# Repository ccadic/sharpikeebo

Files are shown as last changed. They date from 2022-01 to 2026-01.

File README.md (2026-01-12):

**SHARPIKEEBO – Version 2025 (Public Release)
**
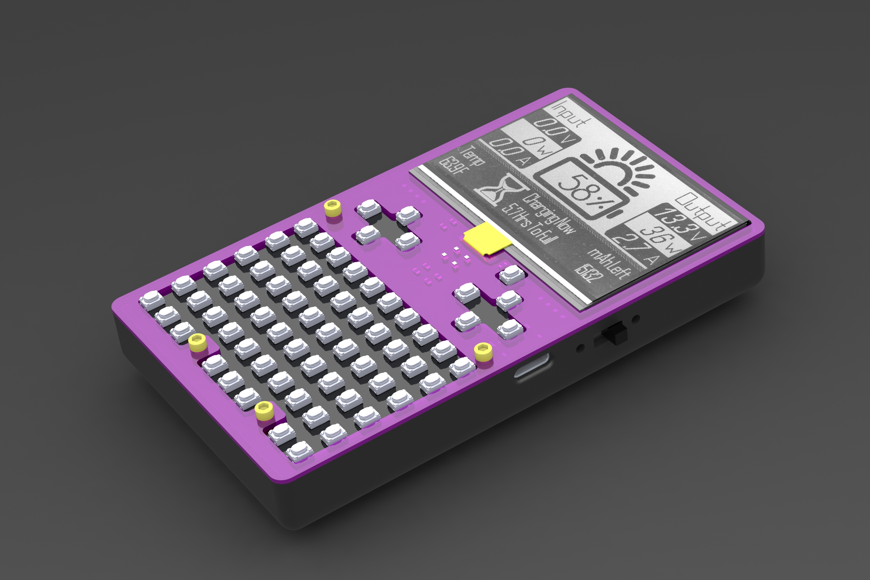
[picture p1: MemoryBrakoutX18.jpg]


**sharpikeebo – V2025
Miniature Raspberry Pi Zero 2W shield with Sharp Memory Display and USB Keyboard
**
This repository now documents the public 2025 version of the SHARPIKEEBO, distributed after the successful crowdfunding campaign on
Crowd Supply: https://www.crowdsupply.com/morpheans/sharpikeebo

All hardware described here corresponds to the final production version delivered to backers and the public.

Overview

Hello all,

This is the SHARPIKEEBO Nano Computer Shield, built around the famous Raspberry Pi Zero 2W, featuring:

- A high-quality Sharp Memory Display (400 × 240 pixels)
- A true USB keyboard, powered by QMK firmware
(https://docs.qmk.fm/#/)
- An ATmega32U4 microcontroller
- A compact form factor designed as a real miniature Linux terminal

The SHARPIKEEBO was initially designed as a portable SSH and system administration tool, allowing administrators to quickly connect to servers and perform maintenance operations.
During development, many users also pointed out its potential as a retro or lightweight gaming platform.

**Hardware Description
**

The SHARPIKEEBO carrier board is designed to host:

- A Raspberry Pi Zero 2W or Zero W
- A 2.7" Sharp Memory Display (400 × 240) capable of fast refresh rates, suitable for:
  Linux shells
  Text-based interfaces
  Simple graphical games
  Additional features include:

- Controllable LEDs (GPIO, usable from C++ or Python)
- Easily accessible UART and I²C GPIOs for external modules:
  GPS
  4G / 5G modem
  Other 3.3 V or 5 V peripherals

Power is supplied via USB-C, and the board can also behave as a USB keyboard device when plugged into a desktop, laptop, or rack server.

**IMPORTANT CHANGES & CLARIFICATION (READ CAREFULLY)
**
This section is critical for proper operation of the 2025 public hardware.

**Raspberry Pi Zero mounting orientation (VERY IMPORTANT)
**
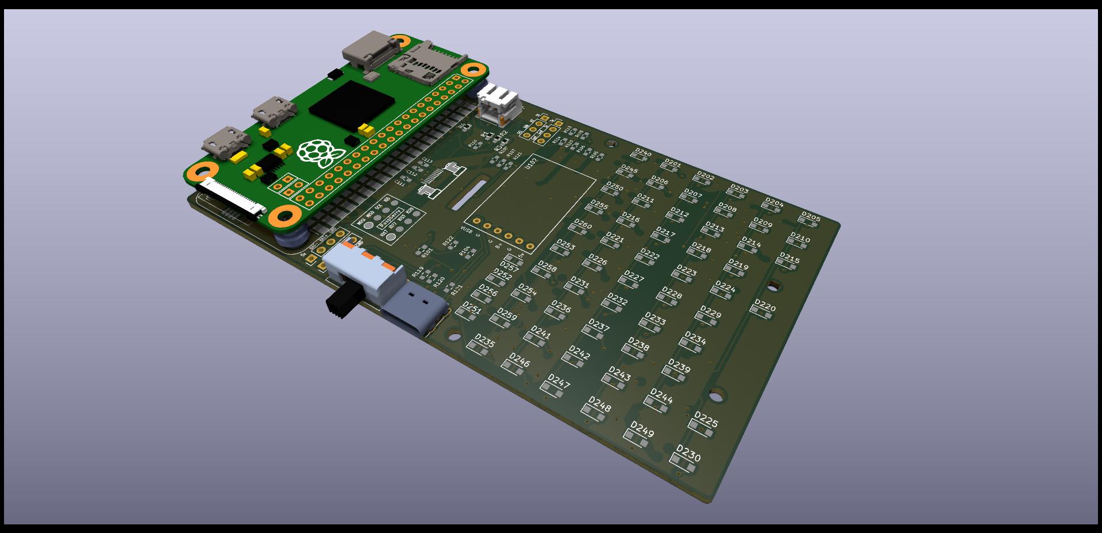
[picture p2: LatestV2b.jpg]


The Raspberry Pi Zero must be mounted with its connector facing DOWN

This means the components of the Raspberry Pi remain visible

DO NOT use a 20×2 pin header mounted on the TOP side

If the Raspberry Pi is connected using a top-mounted 20×2 pin header, the board will NOT work

 This is not optional and is required by the electrical design of the SHARPIKEEBO.

 Battery polarity warning
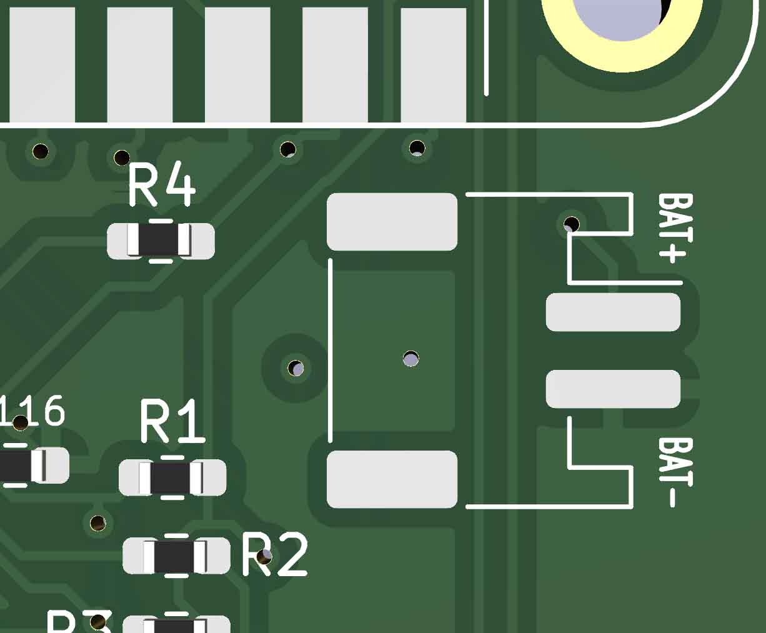
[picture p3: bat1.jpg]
**** 

Some batteries on the market do NOT follow standard polarity orientation

Incorrect polarity can permanently damage the board

 Always verify battery polarity against the schematics before connecting
 Never assume wire colors are correct

**RAK Wireless module interface
**
The RAK Wireless module is connected in UART mode

It is NOT wired in SPI mode

 Any software configuration must therefore use UART, not SPI.
Factory testing guarantee

Every single SHARPIKEEBO unit shipped has been individually tested

All boards were:
- Powered
- Verified
- Confirmed fully functional before shipping

If you encounter an issue, it is almost always related to:
- Incorrect Raspberry Pi mounting
- Battery polarity inversion
- Incorrect peripheral wiring or configuration
- Status

This repository now reflects the final, stable, production hardware shipped after the Crowd Supply campaign.
Future updates will focus on software examples, configurations, and community contributions, not hardware changes.

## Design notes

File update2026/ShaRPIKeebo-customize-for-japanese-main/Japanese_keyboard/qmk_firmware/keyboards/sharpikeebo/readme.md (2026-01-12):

# sharpikeebo

![sharpikeebo]

*A short description of the keyboard/project*

* Keyboard Maintainer: t.hara (https://github.com/hra1129)
* Hardware Supported: *The PCBs, controllers supported*
* Hardware Availability: *Links to where you can find this hardware*

Make example for this keyboard (after setting up your build environment):

    make sharpikeebo:default

Flashing example for this keyboard:

    make sharpikeebo:default:flash

See the [build environment setup](https://docs.qmk.fm/#/getting_started_build_tools) and the [make instructions](https://docs.qmk.fm/#/getting_started_make_guide) for more information. Brand new to QMK? Start with our [Complete Newbs Guide](https://docs.qmk.fm/#/newbs).

## Bootloader

Enter the bootloader in 3 ways:

* **Bootmagic reset**: Hold down the key at (0,0) in the matrix (usually the top left key or Escape) and plug in the keyboard
* **Physical reset button**: Briefly press the button on the back of the PCB - some may have pads you must short instead
* **Keycode in layout**: Press the key mapped to `RESET` if it is available

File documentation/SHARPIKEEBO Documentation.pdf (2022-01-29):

# SHARPIKEEBO 1.0

RASPBERRY PI ZERO + SHARP LS027B7DH01 Memory Display Carrier Board + USB ATMEGA34U Keyboard

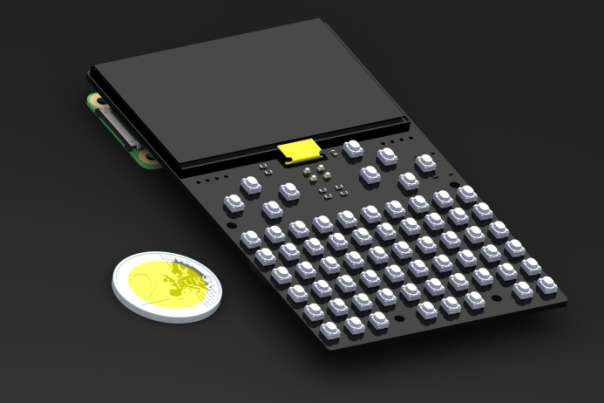
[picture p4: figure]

Description

The SHARPIKEEBO carrier board has been designed to hold both a Raspberry(R) PI ZERO 2W or W + 2.7" (400x240) Sharp Memory Display. This display is capable of a fast refresh which allows the use of linux shells or display game images. A true USB Keyboard (driven by QMK firmware, so fully customized) has been added on the board.

The board also has 4 independently controllable LEDs you can switch on/off with classic GPIO commands (C++ or Python)

The board also has 5 buttons you may also control via GPIO voltage detection (UP/Down voltage detection). You can use this board for gaming.

And more, you have UART GPIO and I2C GPIO easily available on board should you want to add a 3.3v or 5v module such a GPS , 4g or 5g modem etc ...

The board + RPI can be powered thought a USB C connector. The board has also been design to behave as a USB keyboard you can plug on a desktop or laptop or rack server.

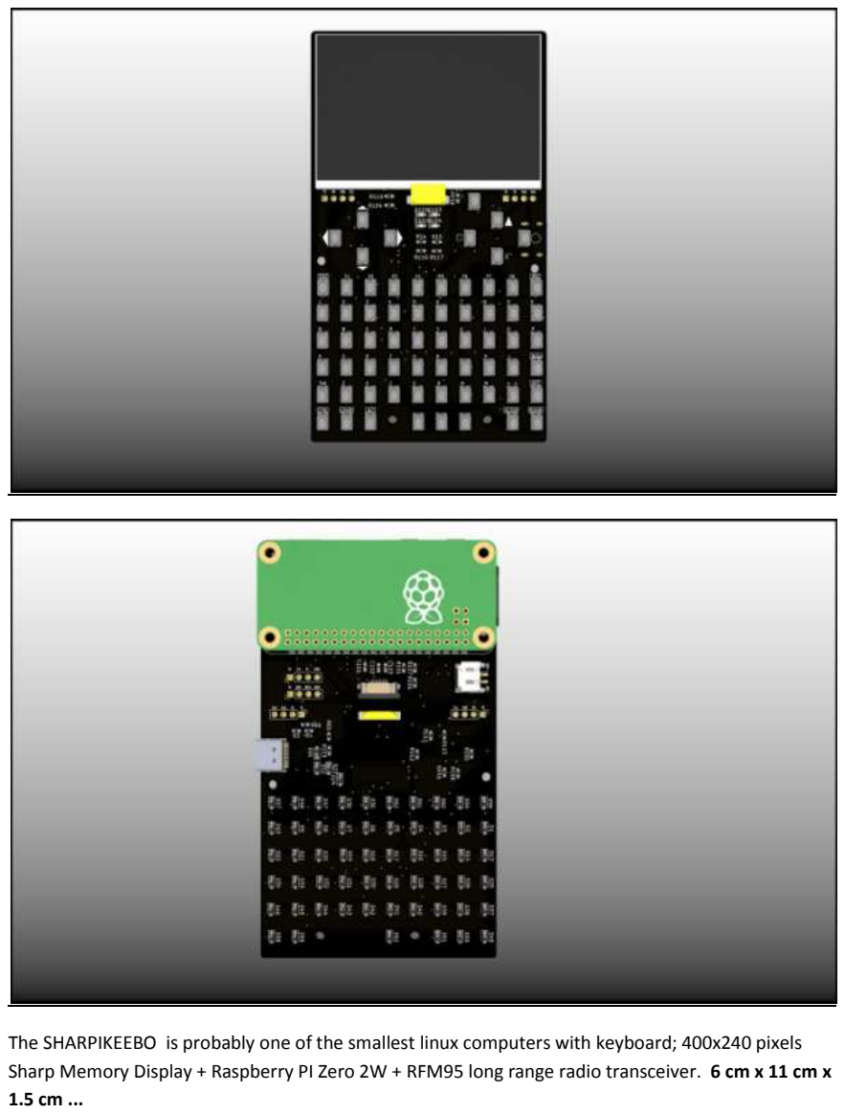
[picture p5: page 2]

The SHARPIKEEBO is probably one of the smallest linux computers with keyboard; 400x240 pixels Sharp Memory Display + Raspberry PI Zero 2W + RFM95 long range radio transceiver. 6 cm x 11 cm x 1.5 cm ...

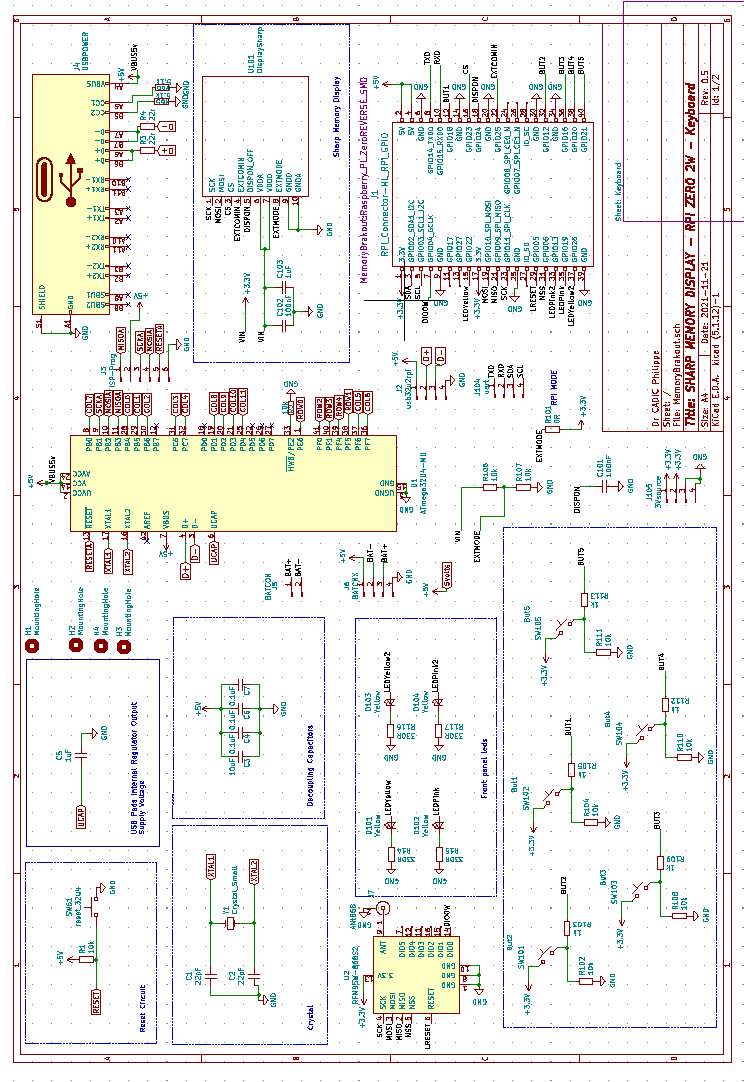
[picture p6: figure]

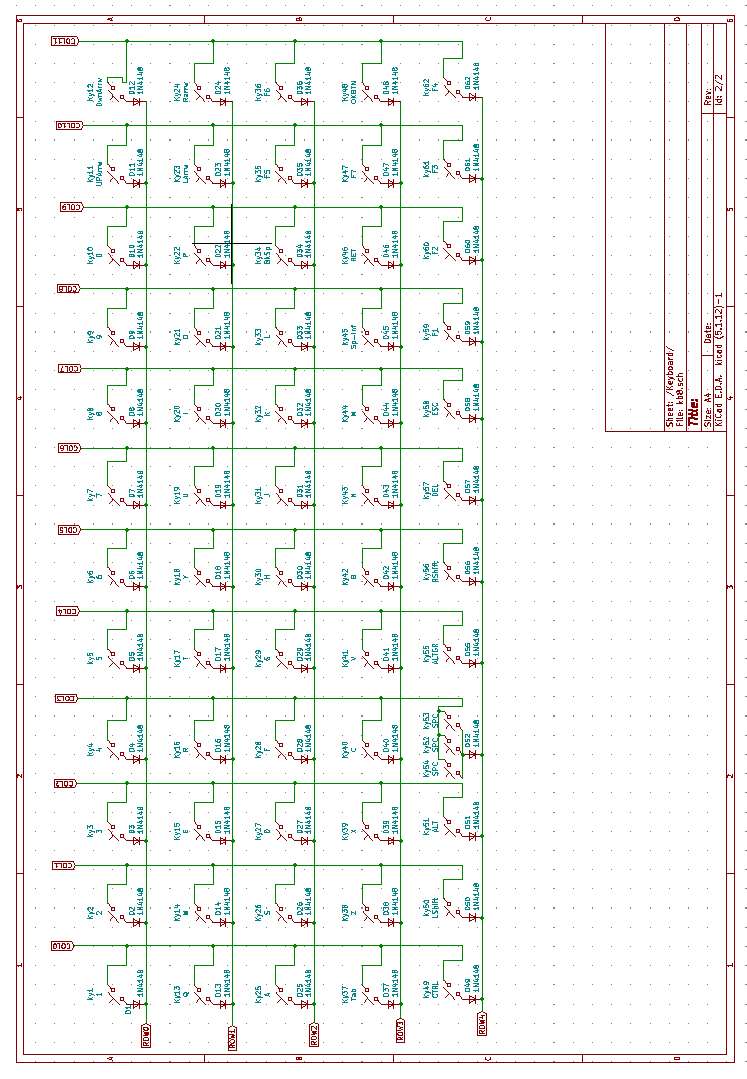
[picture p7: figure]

Extra GPIO available

We added several extra GPIO, should you want to add an external UART extra board or a I2C board. For the maker, we also added access to the display pins with the right bottom line of 2.54 mm header pinout (SCK to GND). If you want, you can drive the LCD without the Raspberry PI ZERO , and replace it with a classic microcontroller. In the same idea, you have B1 to B5 buttons signals available on pins.

You get all the necessary connectors to add a battery charger , should your want to add a lipo and build a autonomous device or drive a 3G/4G/5G modem which require a lipo for energy reasons.

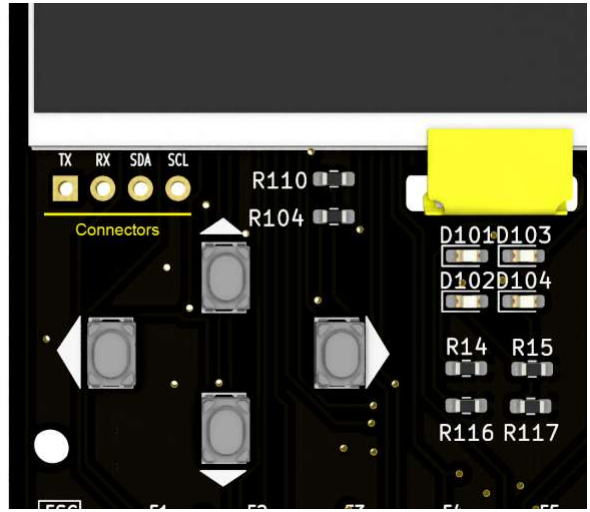
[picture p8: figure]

On the left you get 4 pins to connect a UART optional module or an I2C sister board. For example, you can add an optional display with the I2C interface, a GSM module such as SIM800L or newer which is often compatible with UART, an accelerometer … etc etc …

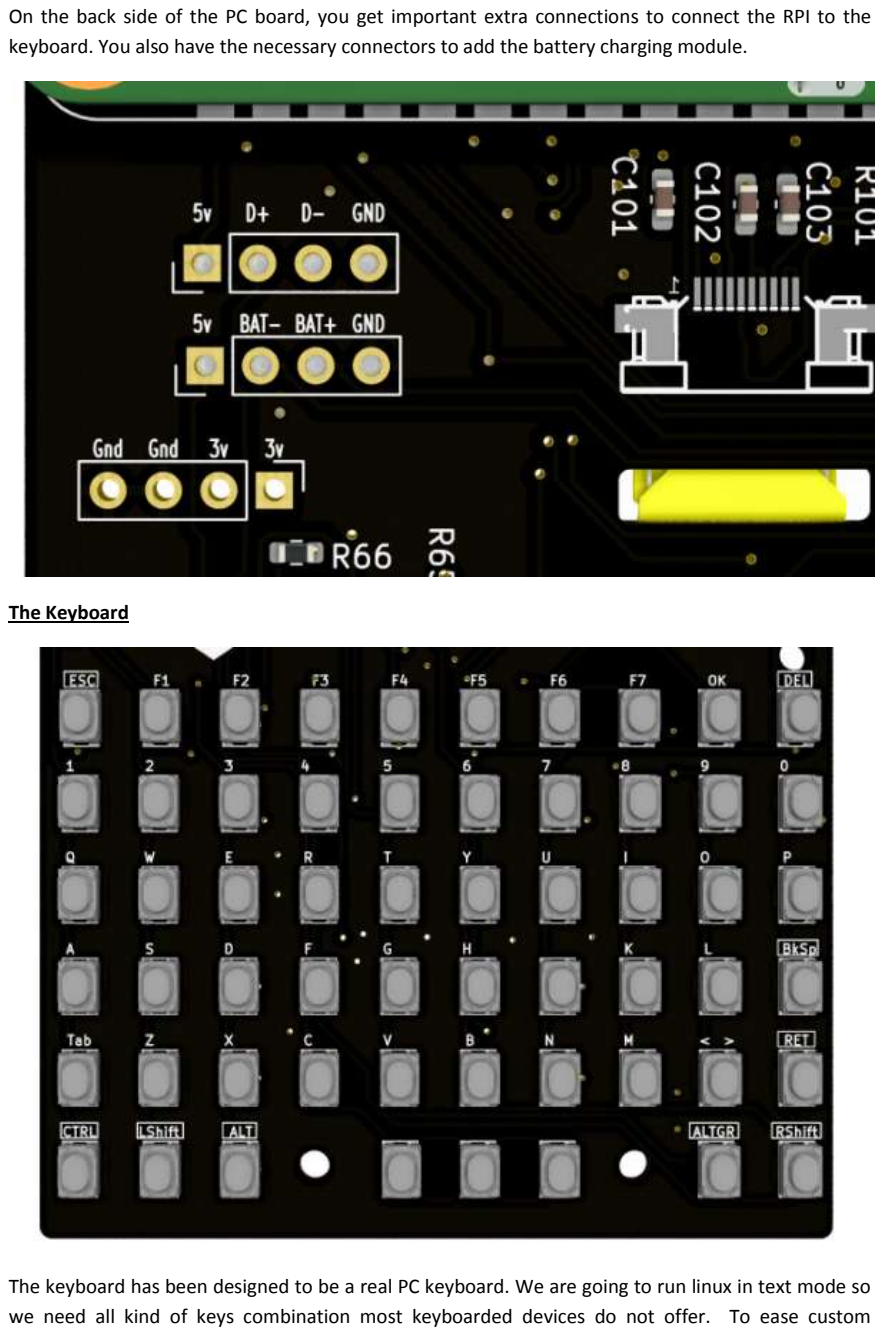
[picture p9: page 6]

On the back side of the PC board, you get important extra connections to connect the RPI to the keyboard. You also have the necessary connectors to add the battery charging module.

The Keyboard

The keyboard has been designed to be a real PC keyboard. We are going to run linux in text mode so we need all kind of keys combination most keyboarded devices do not offer. To ease custom configuration , we decided to let the keyboard behave as a classical USB device you just plug into the RPI. For this, the ATMEGA32U4 chip is used. We flashed the QMK opensource firware so it can work right out of the box. Now , with QMK, you can modify the keys to any one or any script you wish.

Two joypads

Should you want to work on a port of a game system, we kept 2 joypads with 9 buttons. It will then be possible for game developers to adapt their work onto SHARPIKEEBO.

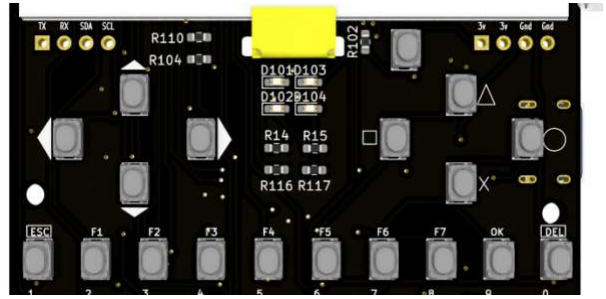
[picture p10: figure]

The radio module for long range communications

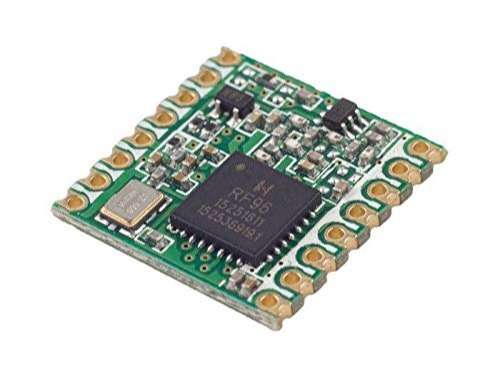
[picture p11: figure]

Installation

If the board and display come separate, please connect the display's ribbon to the white connector, ribbon contacts facing the board surface.

Software setup

The Buttons and LEDs are controllable using classic python scripts.

For the display, you have to install 2 libraries/code and compile them

1° ONE BITE DISPLAY LIB: https://github.com/bitbank2/OneBitDisplay

Install with git clone https://github.com/bitbank2/OneBitDisplay

Go to /linux/Sharp_LCD directory and type make.

2° ARMBIANIO LIB: https://github.com/bitbank2/ArmbianIO

Install the lib with git clone https://github.com/bitbank2/ArmbianIO

and make

Go back to Go to /linux/Sharp_LCD directory and run the compiled executable ./sharp_lcd

Have fun !

Dr CADIC Philippe

Special credits to : Larry Bank for hi precious help and support in this project. @fast_code_r_us

Link to new LCD if an accident occurs

Link to SHARP Display: https://fr.aliexpress.com/item/4000674316500.html

QMK Firmware : https://docs.qmk.fm/#/

Link to battery module: https://fr.aliexpress.com/item/32999118705.html

Link to RFM95 Radio module: https://www.digikey.fr/fr/products/detail/rf-solutions/RFM95W-868S2/5051755

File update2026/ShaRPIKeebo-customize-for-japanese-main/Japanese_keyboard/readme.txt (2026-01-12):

ここでは、キーボードをカスタマイズして日本語キーボードに変更する方法をまとめておきます。

1. PC に USBキーボードとして認識させる
	Keeboの On/Off を何らかの手段で接続して下さい。(connect.jpg)

	次に Keeboのキーボード面に向かって右側側面に付いている USB-Cポートに USBケーブルを接続し、
	そのケーブルの反対側を PC に接続します。(front_view.jpg)

	この時点で、USBキーボードとして認識します。

2. QMK をセットアップする
	下記のサイトにセットアップの方法が記載されているので、それに従って WSL上に環境を構築する。
	https://docs.qmk.fm/#/newbs_getting_started

3. デフォルトキーマップをコピーする
	cd /home/{ユーザー名}/qmk_firmware/keyboards/
	mkdir sharpikeebo
	cd sharpikeebo

	下記のサイトに置いてある rules.mk と And defaultlayout.c
	https://hackaday.io/project/181572-blakrpi-2k/log/198948-qmk-compatible-kb-atmega32u4

2. QMK Tool Box をインストールする
	下記の場所にインストーラーが置いてあるので、ダウンロード＆インストール。
	https://github.com/qmk/qmk_toolbox/releases

2. QMK Configurator に接続する
	Keebo を繋げた PC で、QMK Configulator に接続します。

	QMK Configurator
	https://config.qmk.fm/#/pearlboards/zeus/LAYOUT_all

	QMK とは、カスタマイズ可能な USBキーボードファームウェアで、Keebo のキーボード制御用AVR
	には、これを書き込んでおきます。

	※ 私は液晶パネル・バッテリー・ラジオモジュール以外の部品が取り付けられた基板をいただきました。
	   QMKファームは、すでに書き込まれた状態で送られてきたので、ケーブルを繋げるだけでキーボード
	   として認識しました。
	   ご自身で、AVRを取り付けた場合は、QMKファームを書き込むところからやる必要がありますが、
	   その方法については、本家の Document に書かれていますので、ここでは省きます。
	   その辺りは完了している前提です。

	下記の場所に ShaRPIKeebo のキーマップデータが置いてあります。
	https://hackaday.io/project/181572-blakrpi-2k/log/198948-qmk-compatible-kb-atmega32u4

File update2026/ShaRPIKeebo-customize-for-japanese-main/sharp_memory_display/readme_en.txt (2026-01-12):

Display terminal contents on SharpMemoryDisplay
-------------------------------------------------------------------------------
1. Introduction
	SharpMemoryDisplay can be connected to ShaRPIKeebo.

	https://ja.aliexpress.com/item/4000388720940.html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,scm-url:1007.36264.271383.0,pvid:878723cf-f182-4217-af85-68a78912f9c0,tpp_buckets:668%232846%238115%232000&pdp_ext_f=%257B%2522sku_id%2522%253A%252210000001588574748%2522%252C%2522sceneId%2522%253A%252226264%2522%257D&pdp_pi=-1%253B2699.0%253B-1%253B-1%2540salePrice%253BJPY%253Brecommend-recommend

	However, this is a type of display that cannot be displayed without sending data via SPI.
	There is a program sharp_terminal that transfers the contents of the frame buffer 
	to this SharpMemoryDisplay.
	(*) Private as of March 5, 2022. I was provided with compiled binaries by the author.

	If you have this sharp_terminal resident as a service at startup and running 
	behind the scenes The contents displayed on the terminal are directly displayed on SharpMemoryDisplay.

2. Settings
	(1) Copy sharp_terminal.service placed here to /etc/systemd/system/.

		$ sudo cp ./sharp_terminal.service /etc/systemd/system/

	(2) Give /etc/systemd/system/sharp_terminal.service the execute attribute

		$ sudo chmod 755 /etc/systemd/system/sharp_terminal.service

	(3) Enable and start the sharp_terminal service

		$ sudo systemctl enable sharp_terminal
		$ sudo systemctl start sharp_terminal

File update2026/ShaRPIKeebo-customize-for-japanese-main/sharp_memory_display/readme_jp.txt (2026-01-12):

SharpMemoryDisplay にターミナルの内容を表示する
-------------------------------------------------------------------------------
1. はじめに
	ShaRPIKeebo には、SharpMemoryDisplay を接続できます。

	https://ja.aliexpress.com/item/4000388720940.html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,scm-url:1007.36264.271383.0,pvid:878723cf-f182-4217-af85-68a78912f9c0,tpp_buckets:668%232846%238115%232000&pdp_ext_f=%257B%2522sku_id%2522%253A%252210000001588574748%2522%252C%2522sceneId%2522%253A%252226264%2522%257D&pdp_pi=-1%253B2699.0%253B-1%253B-1%2540salePrice%253BJPY%253Brecommend-recommend

	しかし、これはSPIでデータを送り込まねば表示できないタイプのディスプレイです。
	フレームバッファの内容を、この SharpMemoryDisplay に転送するプログラム sharp_terminal
	が存在しています。
	(※2022年3月5日現在、非公開。私は作者様からコンパイル済みバイナリを提供いただきました)

	この sharp_terminal を起動時にサービスとして常駐させて、裏で動かしておくと、
	ターミナルへの表示内容がそのまま SharpMemoryDisplay に表示されるようになります。

2. 設定方法
	(1) ここに置いてある sharp_terminal.service を /etc/systemd/system/ にコピーする。
		$ sudo cp ./sharp_terminal.service /etc/systemd/system/

	(2) /etc/systemd/system/sharp_terminal.service に実行属性を与える
		$ sudo chmod 755 /etc/systemd/system/sharp_terminal.service

	(3) sharp_terminalサービスを有効化して起動する
		$ sudo systemctl enable sharp_terminal
		$ sudo systemctl start sharp_terminal

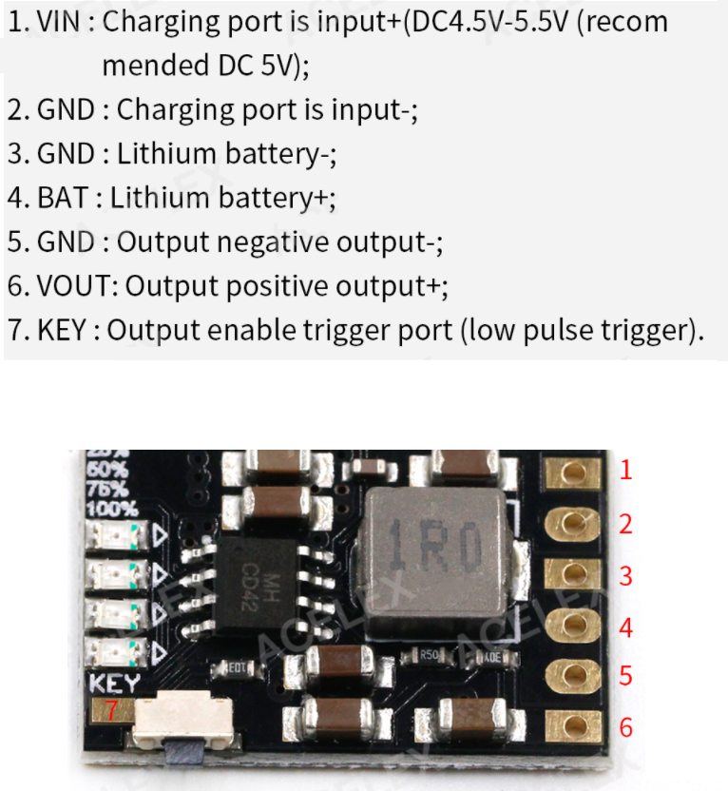
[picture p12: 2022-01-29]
documentation/batmodule.jpg

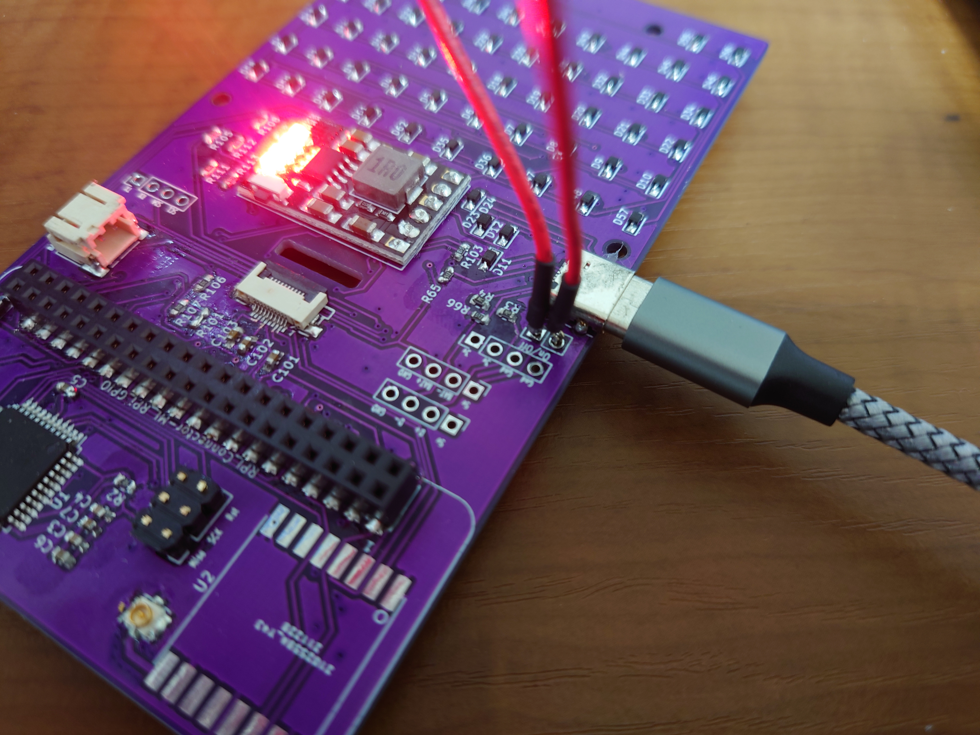
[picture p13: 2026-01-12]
update2026/ShaRPIKeebo-customize-for-japanese-main/Japanese_keyboard/connect.jpg

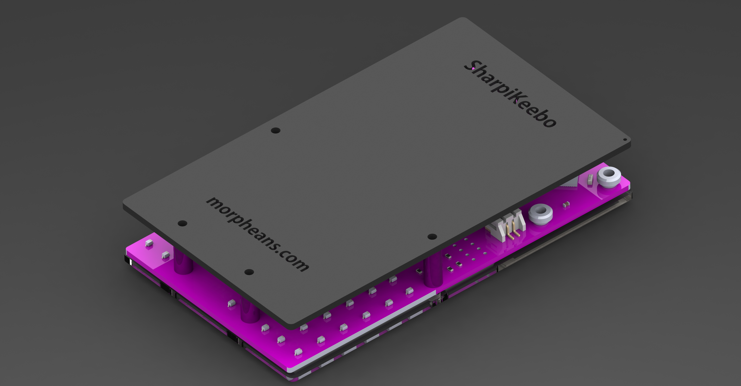
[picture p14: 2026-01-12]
update2026/enclosure2024/Untitled4.JPG

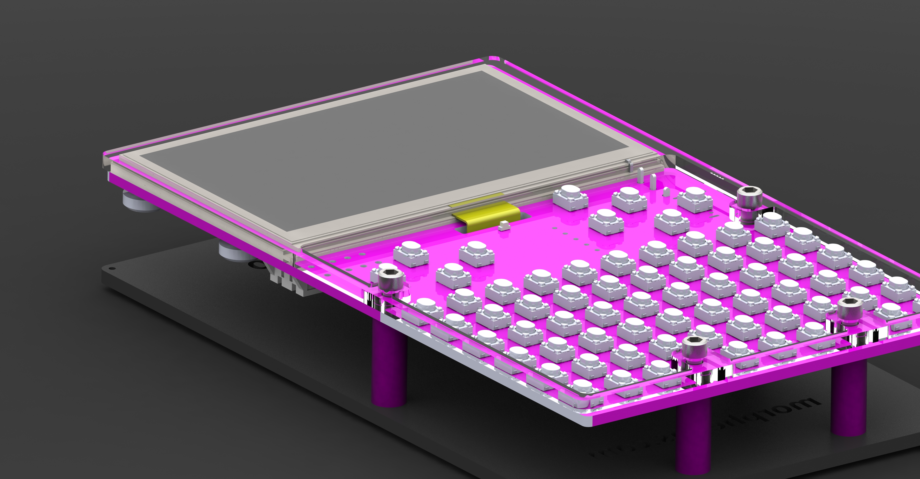
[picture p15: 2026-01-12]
update2026/enclosure2024/Untitled5.JPG

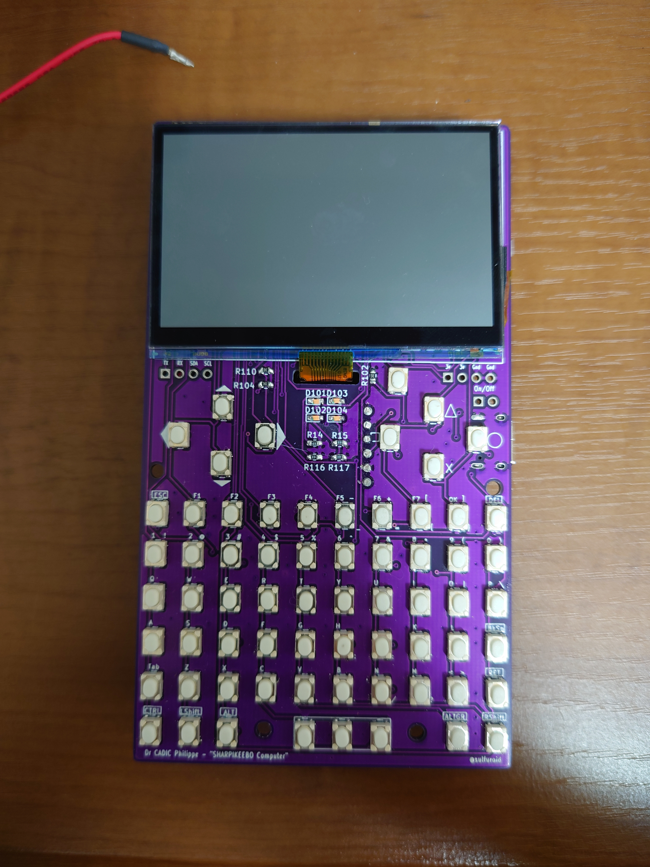
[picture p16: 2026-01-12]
update2026/ShaRPIKeebo-customize-for-japanese-main/Japanese_keyboard/face.jpg

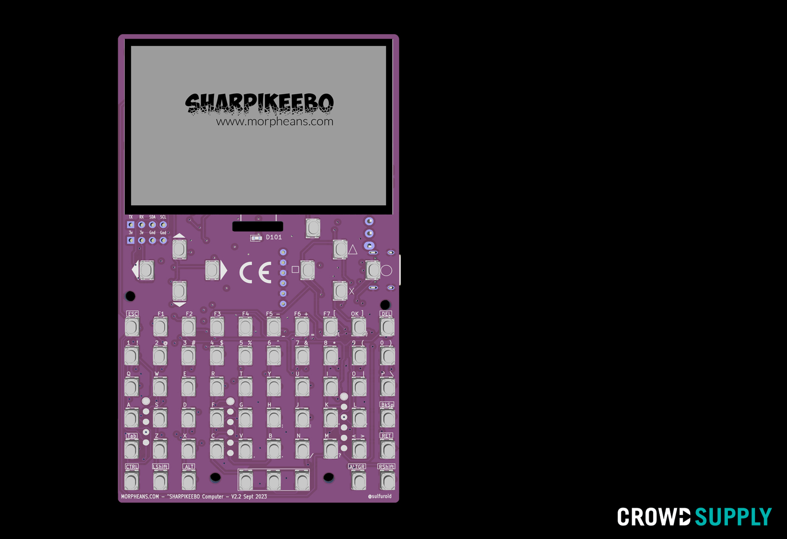
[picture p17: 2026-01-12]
update2026/enclosure2024/etiquetteboite.jpg

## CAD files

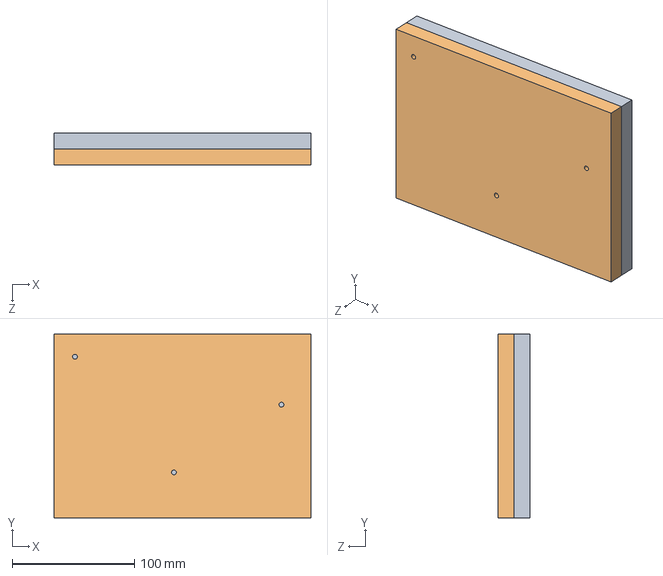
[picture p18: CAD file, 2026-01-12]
update2026/enclosure2024/greatmoule.SLDASM
210.0 x 150.0 x 25.9 mm
mouleinfinjection2
moulesupinjection2

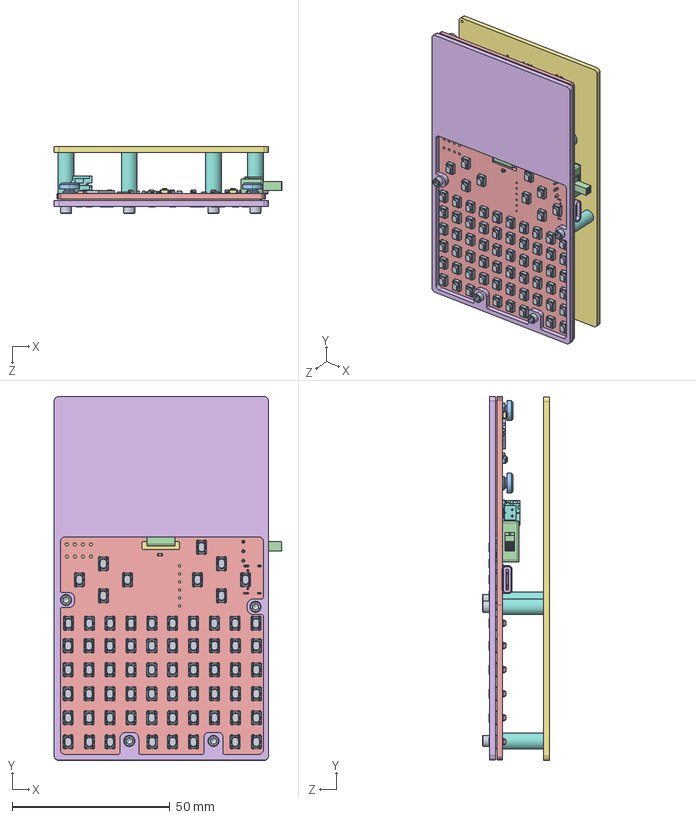
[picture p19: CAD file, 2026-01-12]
update2026/enclosure2023/boxingmars2024.SLDASM
72.2 x 115.4 x 21.3 mm
SOLID.step.STEP x 67
SOLID-0.step.STEP
SOLID-1.step.STEP x 11
SOLID-2.step.STEP x 25
SOLID-3.step.STEP x 60
COMPOUND.step.STEP
SOLID-4.step.STEP x 2
COMPOUND-5.step.STEP
COMPOUND-6.step.STEP
SOLID-7.step.STEP
SOLID-8.step.STEP x 3
COMPOUND-9.step.STEP
MemoryBrakout PCB.step.STEP
coque-dessus
cpoqueinferieure
spacer x 4
socket head cap screw_ai x 4
eBom-prt0.stp
eBom-prt1.stp
eBom-prt2.stp

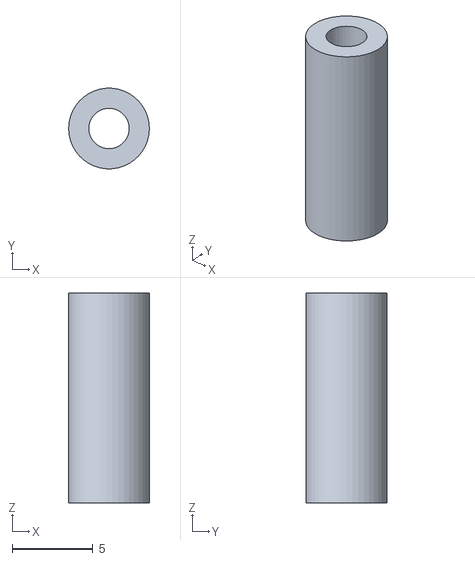
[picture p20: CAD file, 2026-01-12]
update2026/enclosure2024/spacerfull.STL
5.00 x 4.99 x 13.0

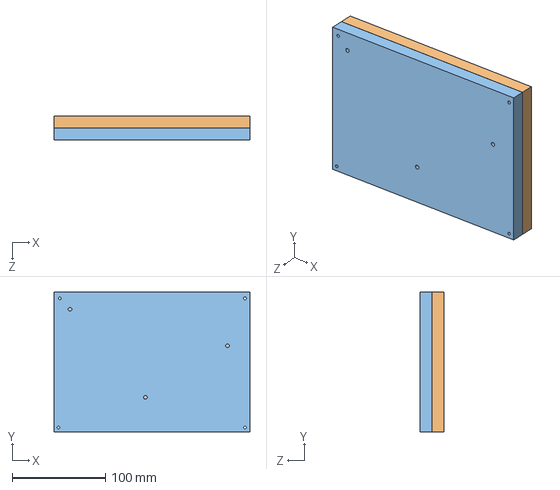
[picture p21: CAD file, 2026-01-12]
update2026/enclosure2024/moule1.SLDASM
210.0 x 150.0 x 26.0 mm
mouleinfinjection
moulesupinjection

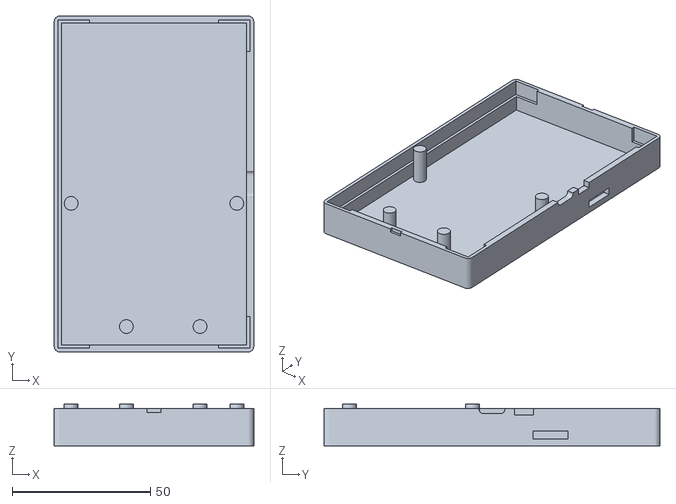
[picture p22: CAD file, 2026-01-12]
update2026/enclosure2023/EPI_down.stl
72.1 x 121.4 x 15.0

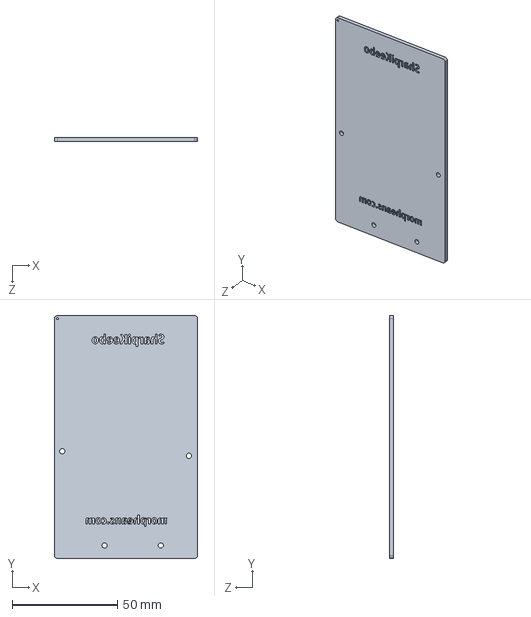
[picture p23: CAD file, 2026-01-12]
update2026/enclosure2024/cpoqueinferieure.SLDPRT
68.0 x 115.3 x 2.00 mm

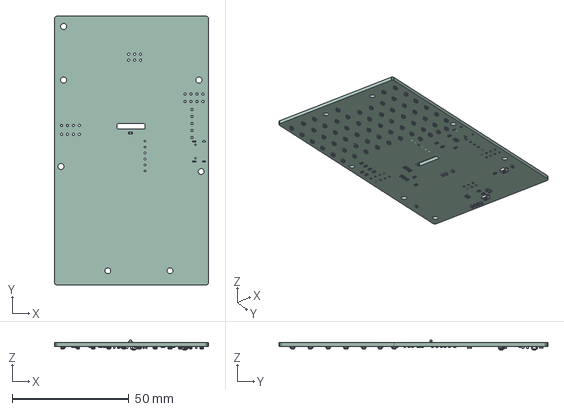
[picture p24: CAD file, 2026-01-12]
update2026/pcbframe.step
66.0 x 115.3 x 4.39 mm
MemoryBrakout PCB

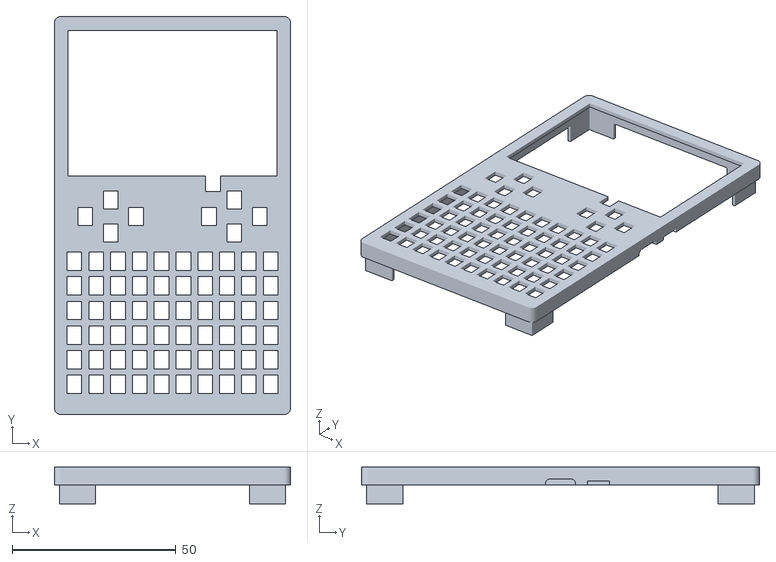
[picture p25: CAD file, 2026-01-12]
update2026/enclosure2023/EPI_up.stl
72.1 x 121.4 x 11.2

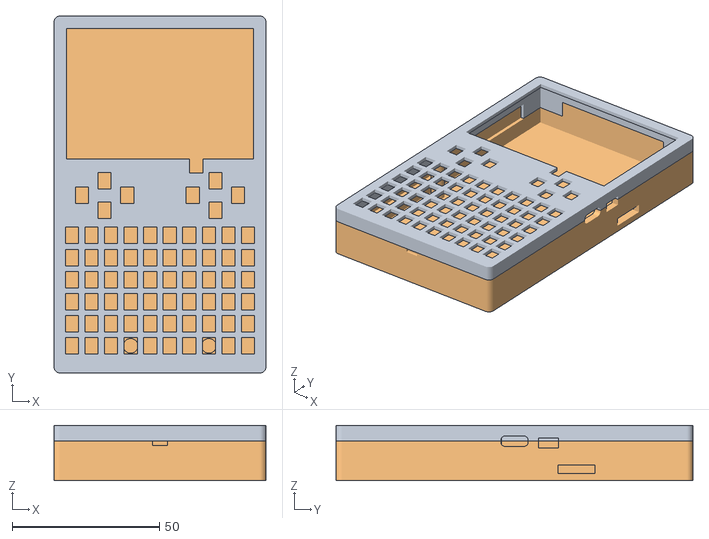
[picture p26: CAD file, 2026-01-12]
update2026/enclosure2023/EPI.obj
72.1 x 121.4 x 18.8

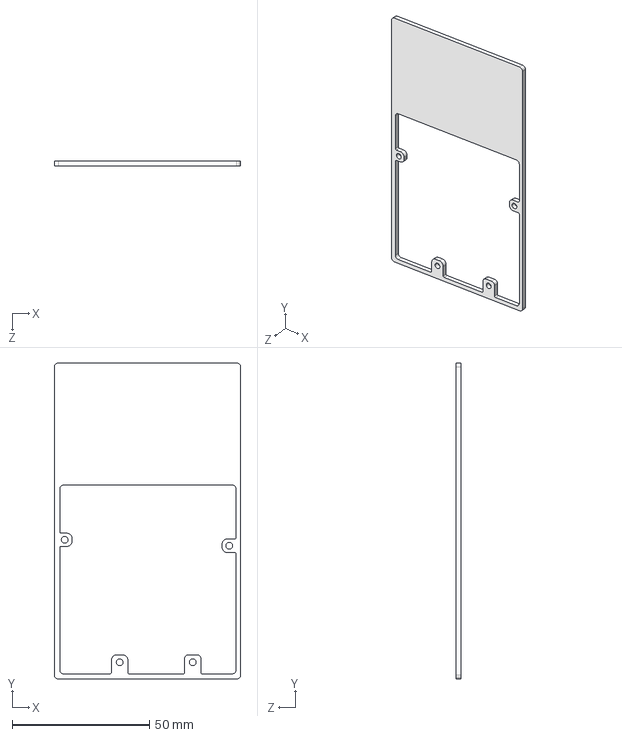
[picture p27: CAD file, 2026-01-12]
update2026/enclosure2024/coque-dessus.STEP
68.0 x 115.3 x 2.00 mm

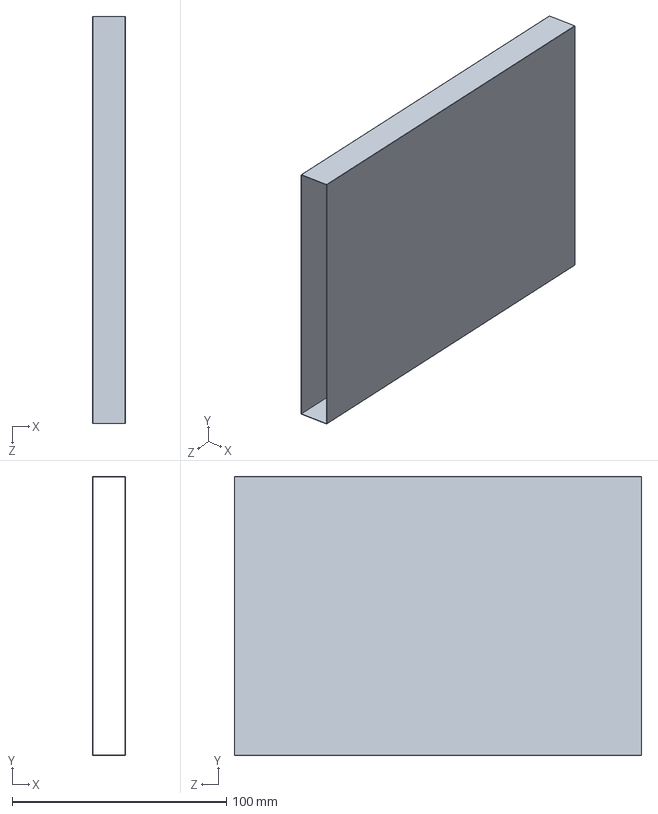
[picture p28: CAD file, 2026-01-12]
update2026/enclosure2024/glissiere.SLDPRT
15.3 x 130.4 x 190.0 mm

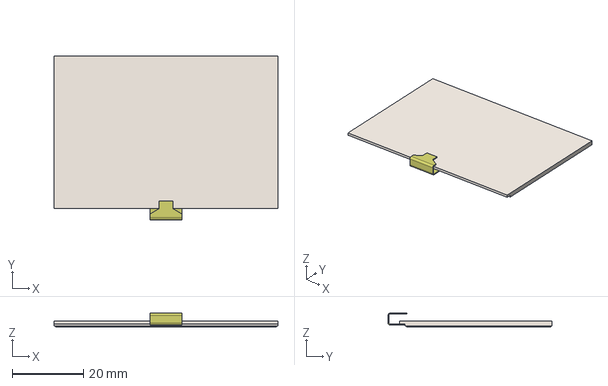
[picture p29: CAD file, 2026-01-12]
update2026/enclosure2024/LS027B7DH01 LCD.stp
62.8 x 46.0 x 3.93 mm

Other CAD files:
update2026/enclosure2023/pcbframe.SLDASM
update2026/enclosure2024/spacer.SLDPRT
update2026/enclosure2023/EPI.f3d
update2026/enclosure2024/LS027B7DH01 LCD.SLDASM
update2026/enclosure2024/LS027B7DH01 LCD.SLDPRT
update2026/enclosure2024/dxf/coque-dessus.DXF
update2026/enclosure2024/dxf/cpoqueinferieure.DXF
update2026/enclosure2024/stl/coque-dessus.STL

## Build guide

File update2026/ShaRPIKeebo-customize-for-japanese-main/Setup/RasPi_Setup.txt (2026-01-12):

1. RaspbianOS のセットアップ
	Raspberry Pi Imager 1.7.1以降を使って RaspbianOS 32bit Lite を microSDカードへインストールする。
		[CHOOSE OS] → [Raspberry Pi OS(other)] → [Raspberry Pi OS Lite (32-bit)]
		[歯車]
			[V] Disable overscan
			[ ]
			[V] Enable SSH
				(V) Use password autherication
			[ ] Set username and password
			[V] Configure wifi
				[SSID] SSID入力
				[ ] Hidden SSID
			[V] Set locale settings
				Time zone : Asia/Tokyo

2. RaspberryPiLite の設定
	2.0. 最初にやること
		$ sudp apt-get update
		$ sudp apt-get upgrade

	2.1. 日本語環境の設定
		$ sudo apt-get install uim-fep uim-anthy fonts-noto-mono fbterm
		$ nano .bashrc

			ファイルの最後に下記を追加して保存する。
			alias fbterm='env LANG=ja_JP.UTF8 fbterm uim-fep'
			export TERM=fbterm
			fbterm

	2.2. CLI のエディタ ne, ファイラー fd をインストールする
		$ sudo apt-get install ne fdclone

	2.3. samba をインストールする
		$ sudo apt-get install samba samba-common-bin
		$ sudo mkdir /share
		$ sudo chmod 777 /share
		$ sudo nano /etc/samba/smb.conf

			ファイルの最後に下記を追加して保存する。
			[share]
			Comment = Pi shared directory
			Path = /share
			Browseable = yes
			Writeable = yes
			only guest = no
			create mask = 0777
			directory mask = 0777
			Public = yes
			Guest ok = yes

			[pi]
			Comment = Pi home directory
			Path = /home/pi
			Browseable = yes
			Writeable = yes
			only guest = no
			create mask = 0777
			directory mask = 0777
			Public = yes
			Guest ok = yes

		$ sudo smbpasswd -a pi
		$ sudo systemctl restart smbd

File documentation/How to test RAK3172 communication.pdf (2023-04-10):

### Morpheans.com / Sharpikeebo

UPDATE : 10/04/2023

HOW TO SET SHARPIKEEBO TO TALK TO THE RAK3172 RADIO MODULE

The RAK3172 is talking to the RASPBERRY PI ZERO via AT Commands. We made the Sharpikeebo capable of using UART1 to talk to the RAK module. TX is GPIO14, RX is GPIO15

To configure the RPI ZERO

Enable UART communications

sudo cp /boot/cmdline.txt /boot/cmdline.txt.old

The original file (fresh installation of Raspberry Pi OS) contains ON A SINGLE LINE:

console=serial0,115200 console=tty1 root=PARTUUID=75afe894-02 rootfstype=ext4 elevator=deadline fsck.repair=yes rootwait quiet splash plymouth.ignore-serial-consoles

Open it with nano (on the Raspberry Pi)

sudo nano /boot/cmdline.txt

Delete this text: console=serial0,115200

And Reboot

sudo reboot

Once rebooted start a

sudo raspi-config

### 1. Go to INTERFACE OPTIONS then SERIAL PORT 2. Select NO on serial login 3. Select YES on ACTIVATE on SERIAL PORT HARDWARE TO BE ENABLE

Then reboot.

sudo reboot

Disable Bluetooth

You need to add a line to the /boot/config.txt file to apply this overlay:

Open the file with nano

sudo nano /boot/config.txt

And at the very bottom of the file, add:

dtoverlay=disable-bt

Save the file and reboot Raspberry Pi OS for the modification to take effect.

sudo reboot

Disable system service

disable-bt that we just used disables the Bluetooth device and makes PL011 (UART0) the primary UART. You also need to disable the system service that initializes the modem so that it doesn't connect to the UART, using the command:

sudo systemctl disable hciuart

Enable the physical UART

In /boot/config.txt if it's not already done automatically, change the line

enable_uart=0

to

enable_uart=1

To take all this into account, reboot your Raspberry Pi

sudo reboot

Install a test terminal software such as minicom

sudo apt install minicom

Start minicom with this command line

minicom -D /dev/ttyAMA0

Set it to the appropriate communication parameters with : CTRL-A P

Set:

- 115200 bauds
- 8 bits of data

- Parity : No parity
- 1 stop bit

and save

Put minicom in ECHO MODE : CTRL-A E

And type ATZ. You should get an answer from the RAK CHIP

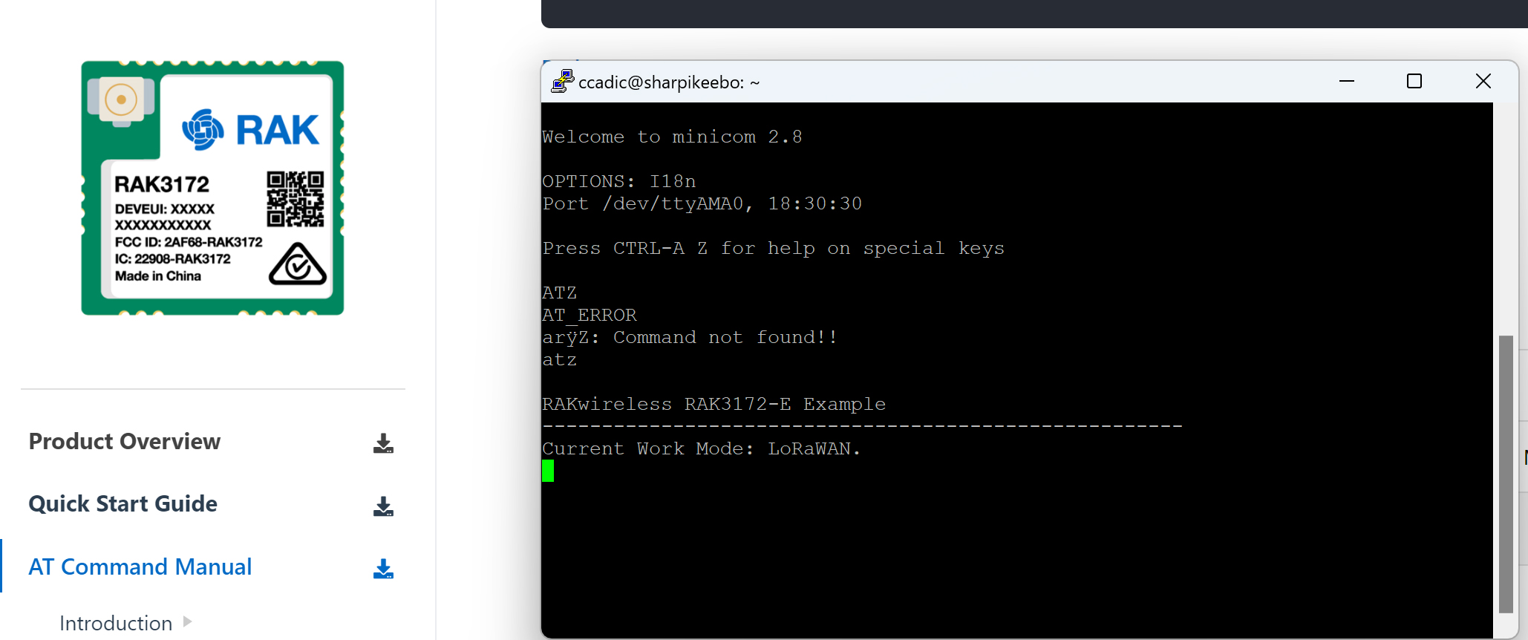
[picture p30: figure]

Your done

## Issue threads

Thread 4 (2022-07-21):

Excellent, but too expensive !

Overscore, 2022-07-21:
150$ + 18$ shipping to Europe + battery + Rpi Zero + case is definitely too expensive !
A real shame!
Quel domage !

ccadic, 2022-07-21:
we understand this point of view. Europe design with european workers and european taxes + european social human protection standards + european work rules + european assembly + european process for certifications + random components prices at the moment due to shortage (obliging to take a security margin). The risk when launching a new device cannot be a suicide :) of course, once posisble we will review when possible.

Overscore, 2022-07-21:
I understand that the company cannot sell at a loss, otherwise there is no more company...  But it's still a shame, I like this product so much.

Je comprends que l'entreprise ne peut pas vendre à perte, sinon il n'y a plus d'entreprise… Mais c'est tout de même dommage, ce produit me plait tellement.

ccadic, 2022-07-21:
yes sure. From the beginning , we are fighting to solve problems. This is another one (the rpi zero is also expesive now :) ) . so we keep fighting... :)
we are at the first stages of this product launch. This is made in the crowdfunding philosophy. Small qties = more expensive prices.  there is nothing we can do about this yet.  but our interest is , yes, to be able to drop the price in a range everyone is happy. with higher quantities, and less component shortage , the production price is obviously going to be better.

oui bien sur. Depuis le début nous nous battons pour résoudre un a un les problemes. Ca n'est qu'un probleme de plus sur lequel de focaliser :)  le rpi zero est devenu tres cher aussi à cause de la penurie
nous somme cependant dans la phase de lancement et dans l'esprit de financement participatif par des early adopters. La petite serie et le choix du moins asiatique possible fait que les prix sont plus elevés.  bien evidemment si les quantites sont plus importantes alors mathématiquement les couts de fabrication baisseront

on y travaille.

bialystok, 2024-05-07:
this is not expensive but this is a loot of money

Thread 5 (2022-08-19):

mc and 12 pt

sp00ck, 2022-08-19:
I'm old man. Can You show mc midnight commander and 12 pt font?
mcedit too (or compare with vi)
show zip (inside mc) or ssh file system (inside mc)
how tiny font must be for 80 chars horisontaly?

glaucus-hauriant, 2023-08-10:
I'm not involved with this project but the display is 400 × 240 px, so to fit 80 chars you'd need a font 5 px wide, including gaps between letters. The pixel pitch is 0.15mm × 0.15mm (172 ppi), so each char would be 0.75mm wide.

I have the same display module on an Adafruit breakout board; the default 5×8 font in their CircuitPython libraries is legible (the pixels aren't blurry or low-contrast) but very small.

(excuse my grubby fingerprints -- I haven't peeled off the protective film)

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

bialystok, 2024-05-07:
mc no need 80 char in line.
12pt is dimension in real world. 1 point	0.3527777778 mm

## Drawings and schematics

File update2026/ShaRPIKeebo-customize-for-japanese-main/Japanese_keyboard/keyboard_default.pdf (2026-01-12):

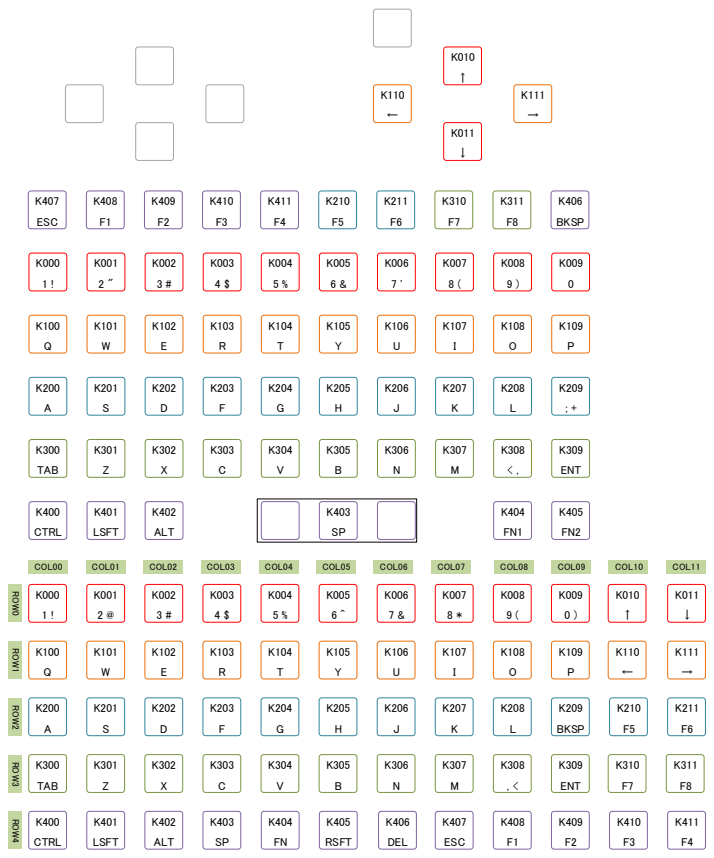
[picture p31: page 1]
ESC; BKSP; TAB; ENT; CTRL; LSFT; ALT; DEL; RSFT; COL00; COL01; COL02; COL03; COL04; COL05; COL06; COL07; COL08; COL09; COL10; COL11; ROW0 ROW1 ROW2 ROW3 ROW4

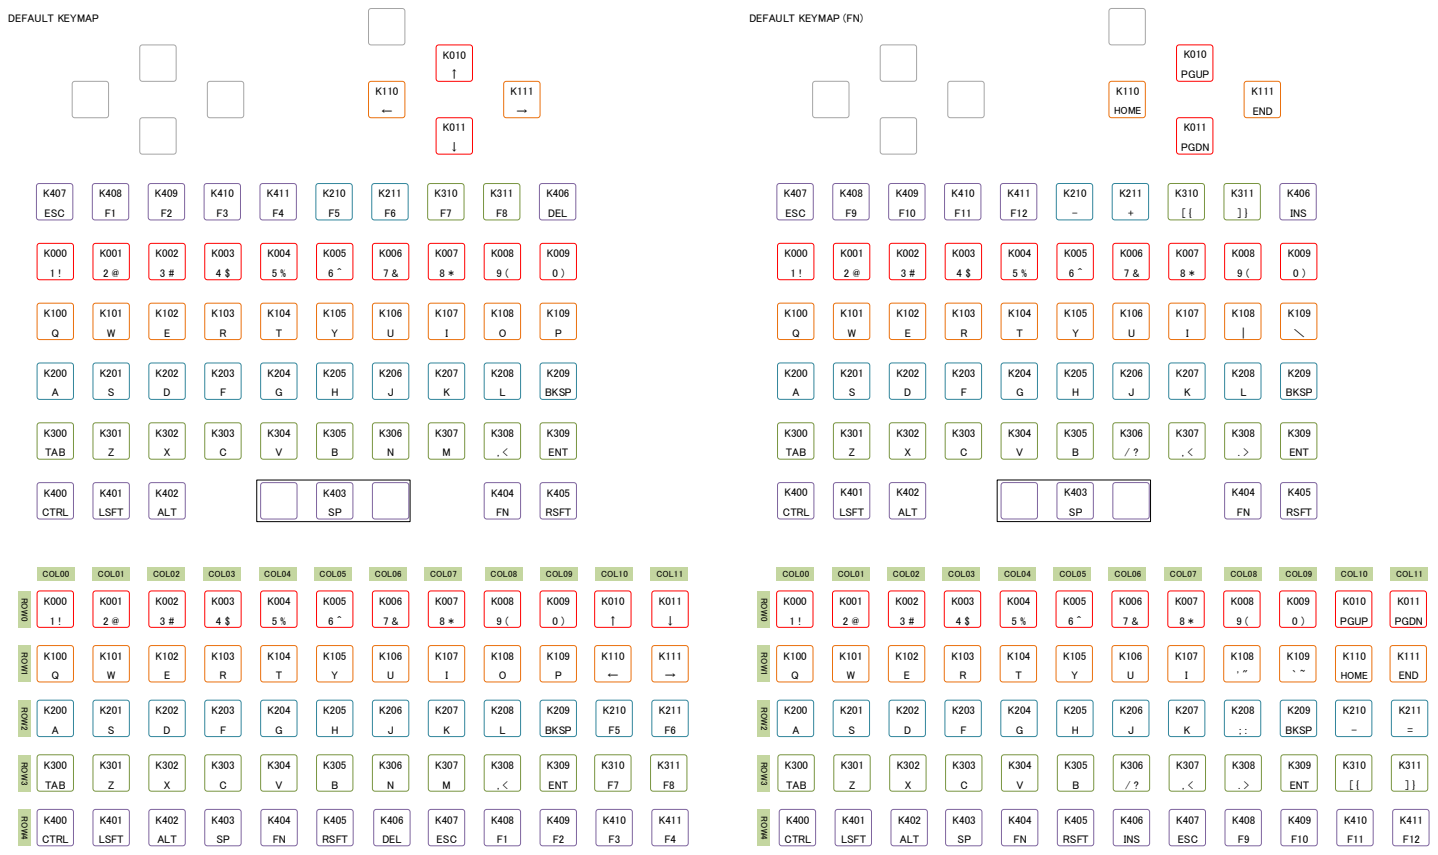
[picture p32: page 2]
BKSP; ESC; DEL; TAB; ENT; CTRL; LSFT; ALT; RSFT; DEFAULT KEYMAP; PGUP; HOME; END; INS; PGDN; COL00; COL01; COL02; COL03; COL04; COL05; COL06; COL07; COL08; COL09; COL10; COL11; ROW0 ROW1 ROW2 ROW3 ROW4

DEFAULT KEYMAP (FN)

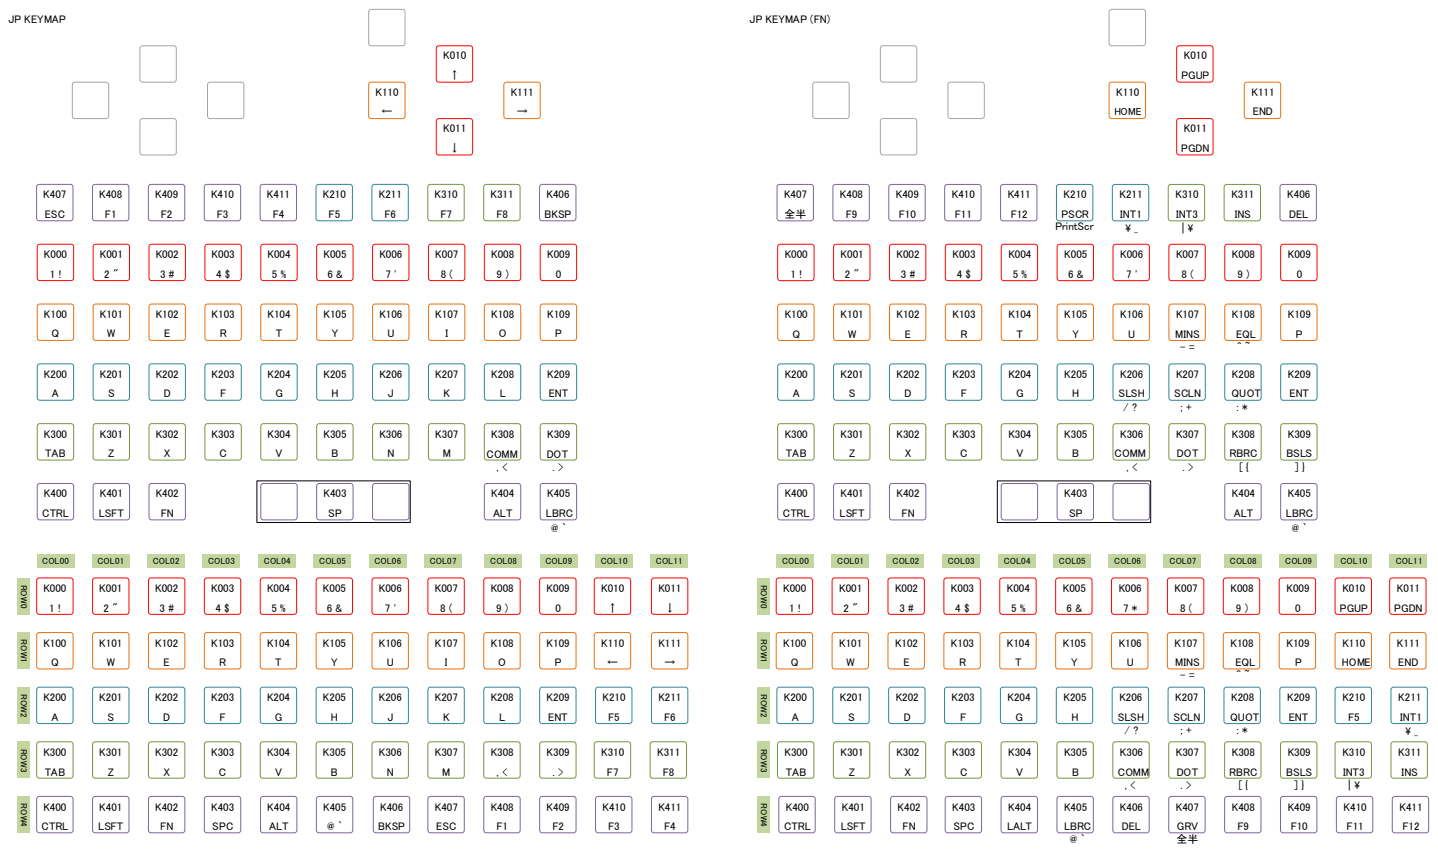
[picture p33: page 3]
ENT; ESC; BKSP; TAB; CTRL; LSFT; ALT; JP KEYMAP; PGUP; HOME; END; PGDN; SLSH; SCLN; QUOT; PSCR; INT1; INT3; INS; DEL; COMM; DOT; RBRC; BSLS; LBRC; SPC; COL00; COL01; COL02; COL03; COL04; COL05; COL06; COL07; COL08; COL09; COL10; COL11; ROW0 ROW1 ROW2 ROW3 ROW4; LALT; GRV; MINS; EQL; INT1 \ _; PrintScr

JP KEYMAP (FN)

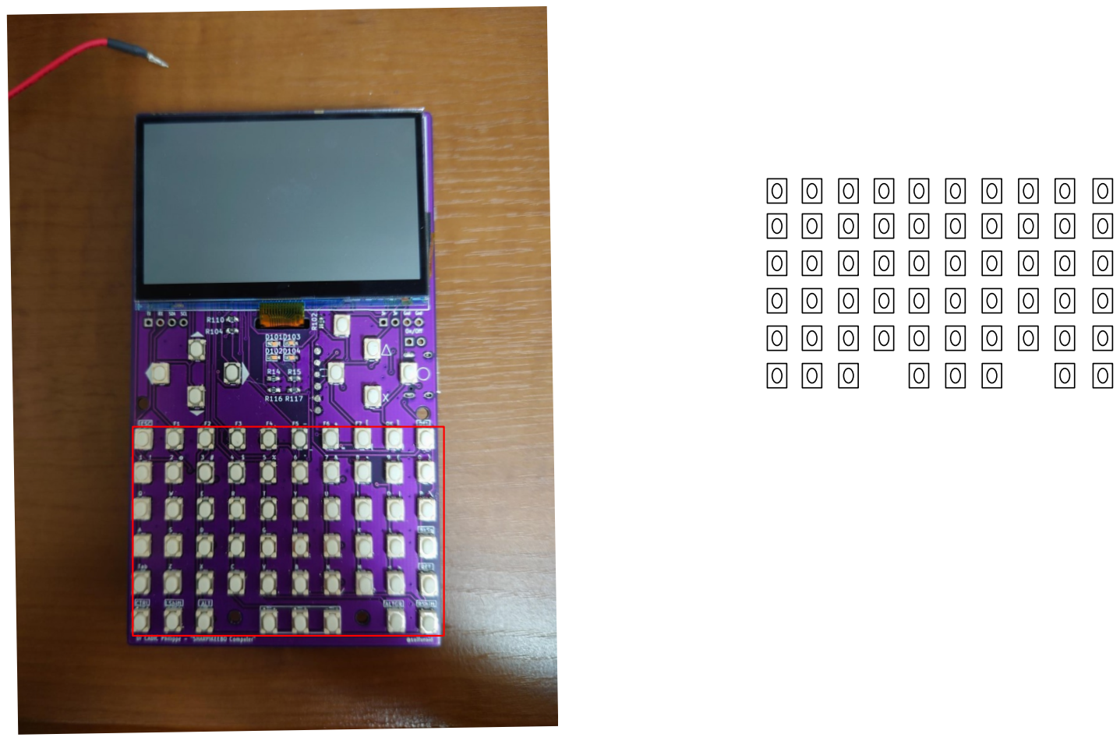
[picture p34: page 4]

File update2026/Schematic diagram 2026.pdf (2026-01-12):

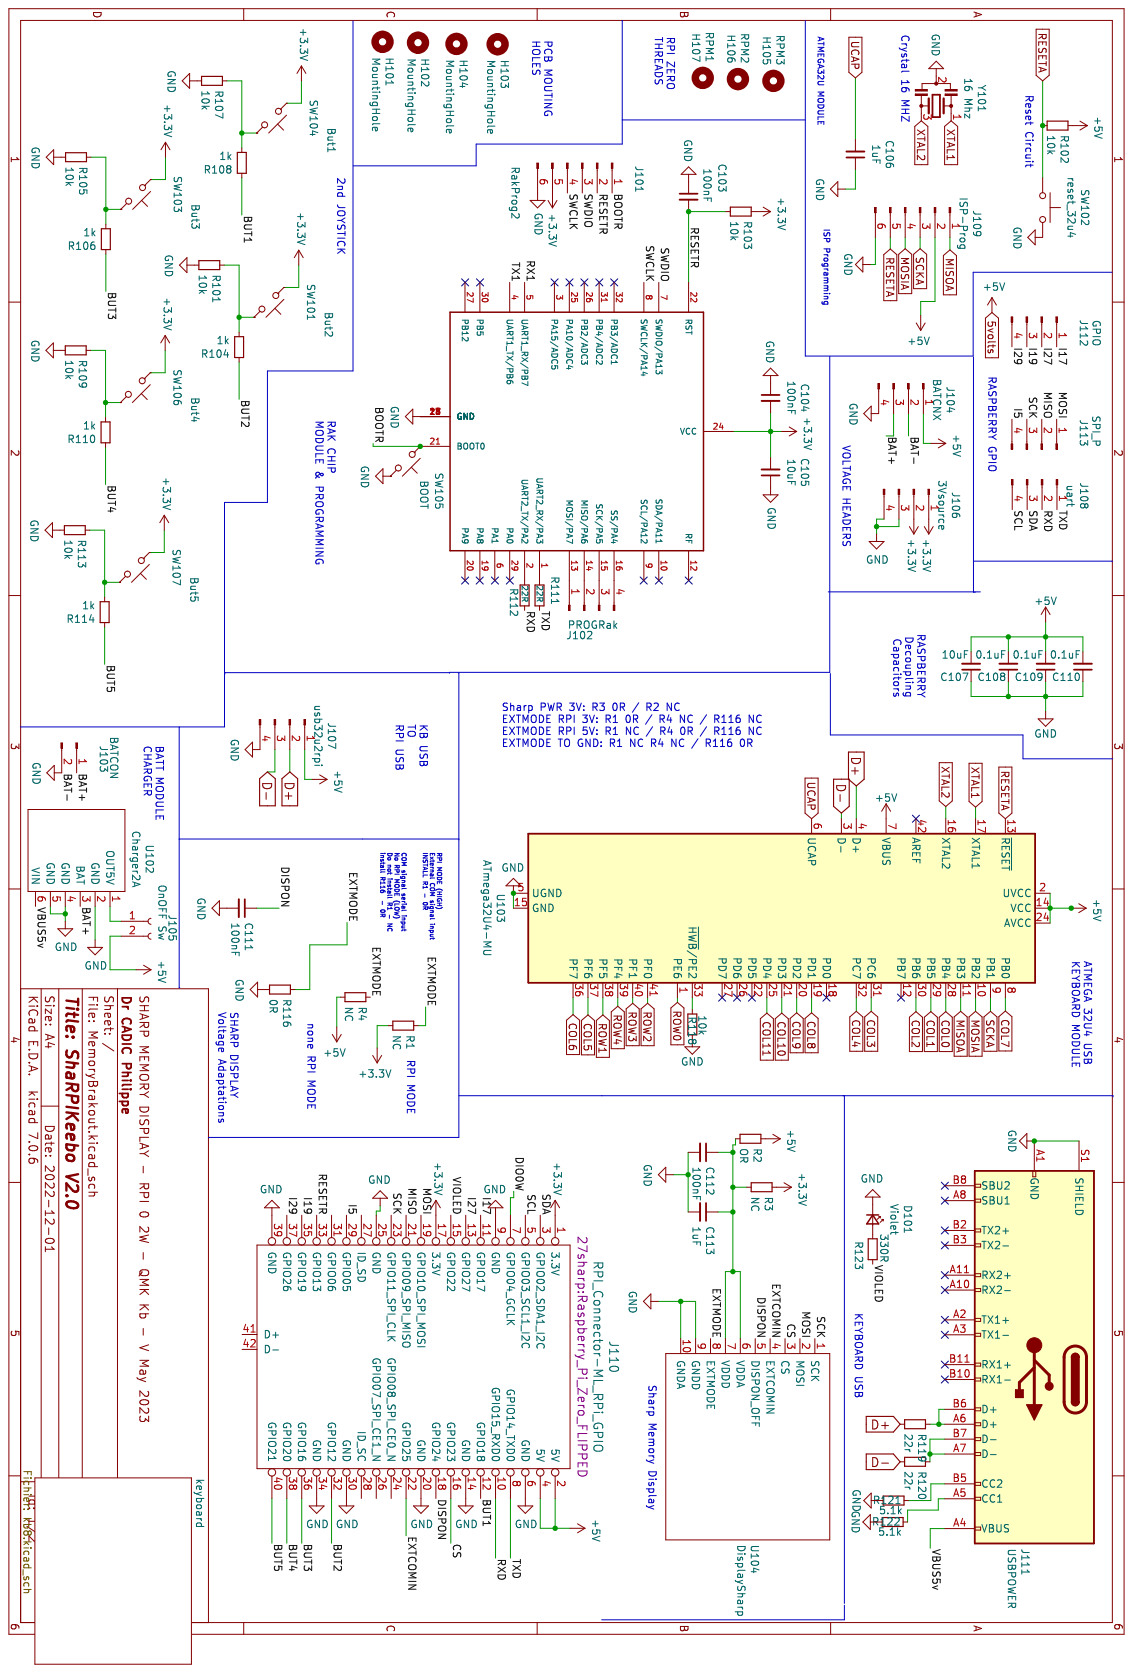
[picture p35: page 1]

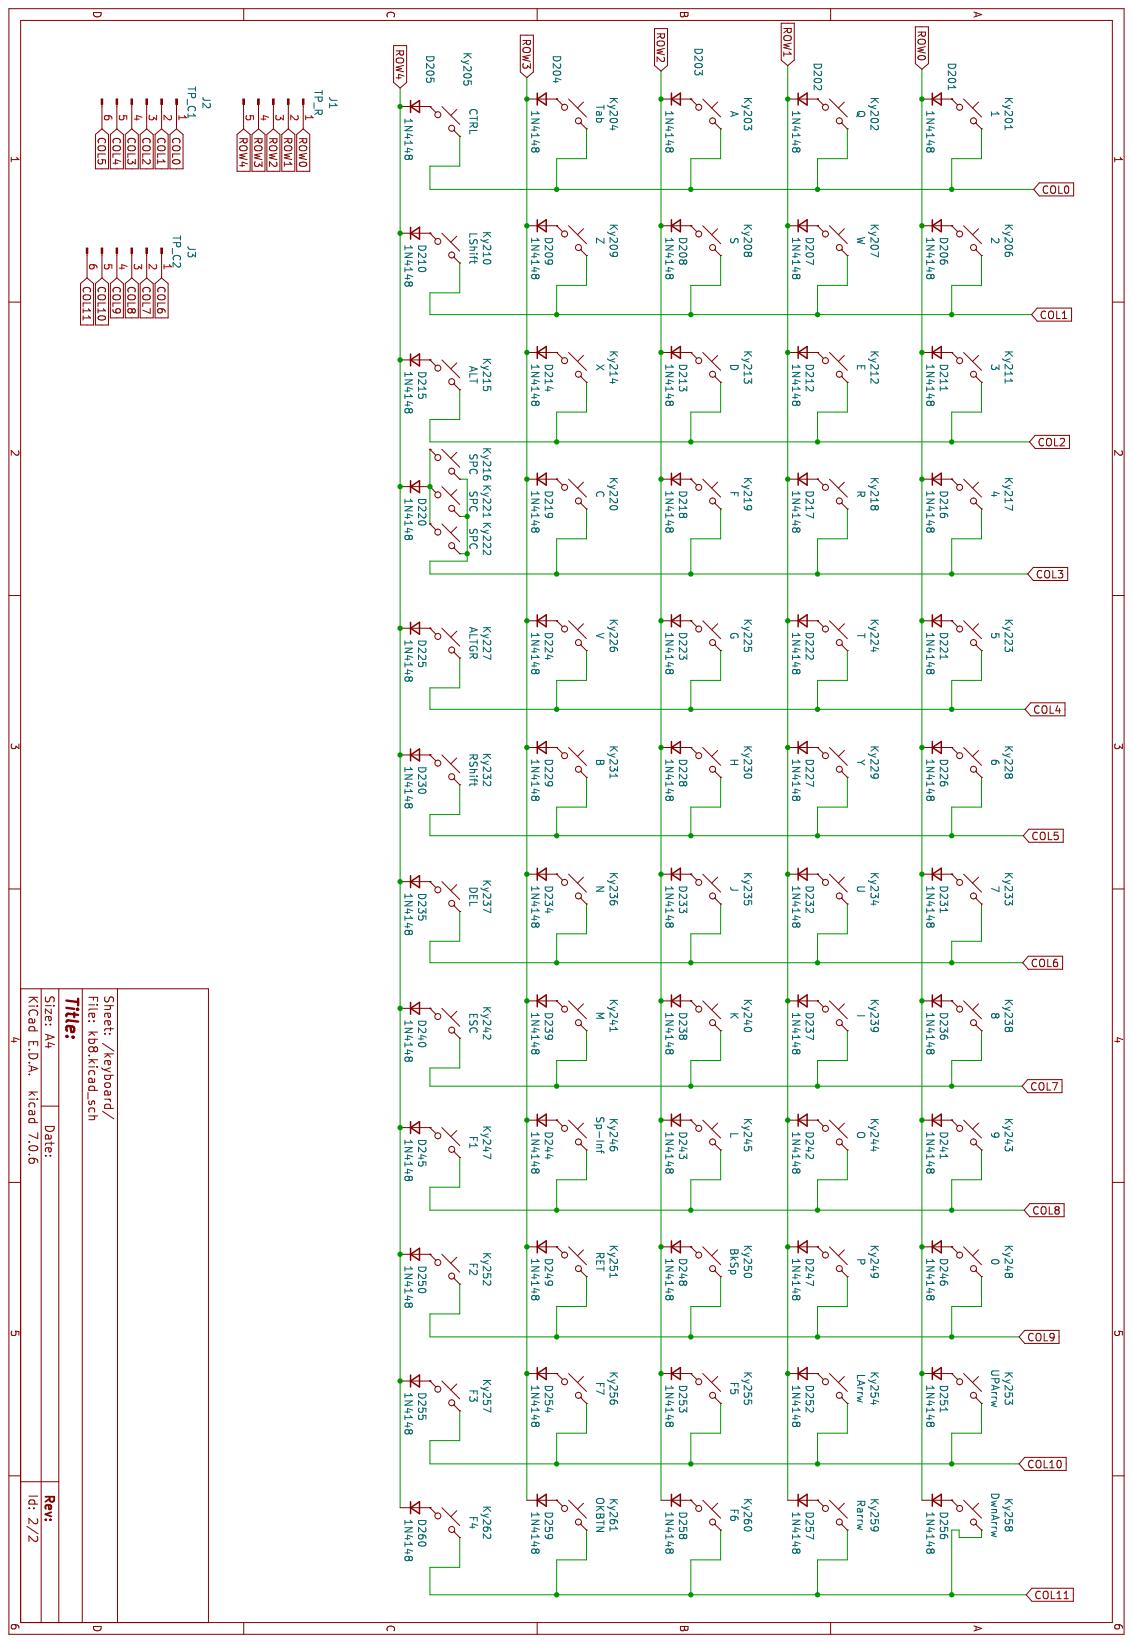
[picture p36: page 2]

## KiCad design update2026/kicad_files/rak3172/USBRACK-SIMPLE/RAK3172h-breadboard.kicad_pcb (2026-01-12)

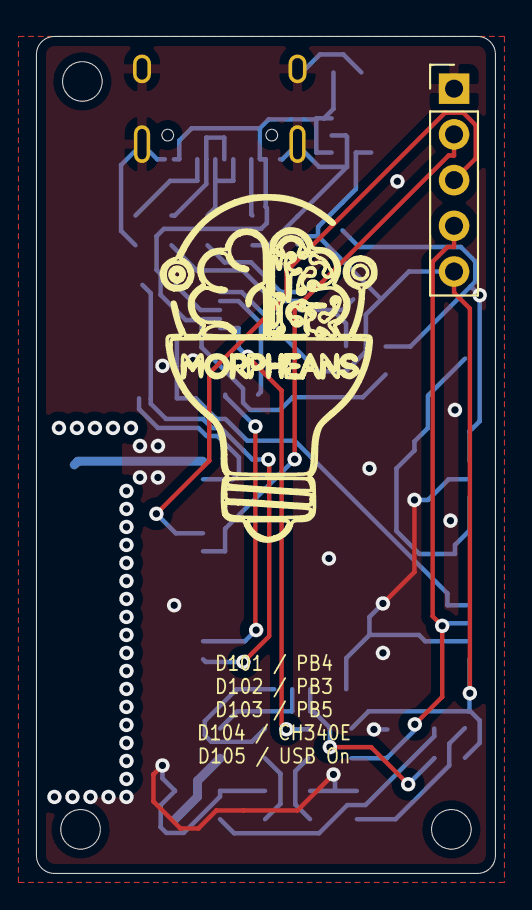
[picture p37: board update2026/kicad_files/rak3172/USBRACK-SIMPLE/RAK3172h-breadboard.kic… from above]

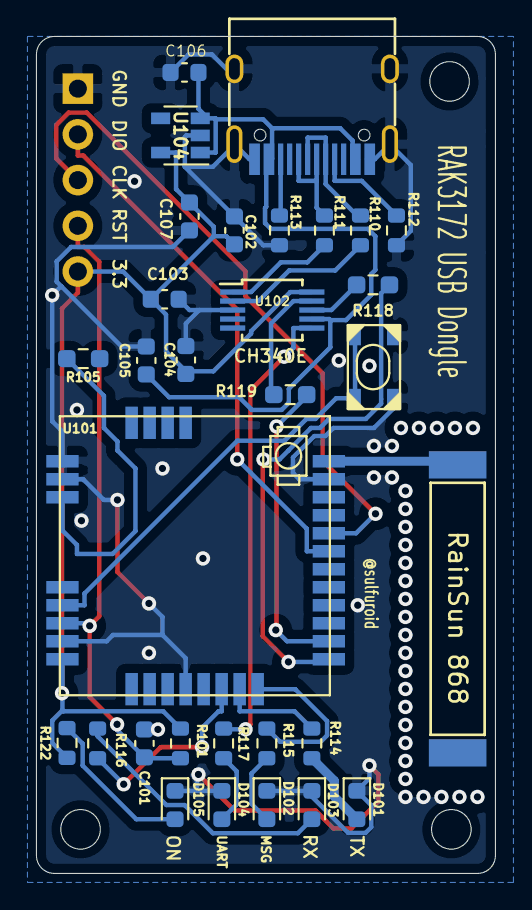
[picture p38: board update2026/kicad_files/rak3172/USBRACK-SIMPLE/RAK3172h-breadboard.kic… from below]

Board: 2 copper layers, 25.5 x 46.5 mm, 35 parts (31 on the bottom side), 28 nets.

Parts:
C101, C102, C104, C105: 100nF; C_0603_1608Metric
C103: 10uF; C_0603_1608Metric
C106, C107: 1uF; C_0603_1608Metric
D101: TX-YEL; LED_0603_1608Metric
D102: GreenL; LED_0603_1608Metric
D103: RX-RED; LED_0603_1608Metric
D104: Violet; LED_0603_1608Metric
D105: ON-LED; LED_0603_1608Metric
H101, H102, H103: MountingHole; MountingHole_2.2mm_M2
J101: Prog_cnx; PinHeader_1x05_P2.54mm_Vertical
J104: USB_C_Receptacle; GT-USB-7010
R101: 10k; R_0603_1608Metric
R105: 1k; R_0603_1608Metric_Pad0.98x0.95mm_HandSolder
R110, R111: 22R; R_0603_1608Metric
R112, R113: 5.1K; R_0603_1608Metric
R114, R115, R116, R122: 330R; R_0603_1608Metric
R117: 1.2k; R_0603_1608Metric
R118, R119: 0R; R_0603_1608Metric_Pad0.98x0.95mm_HandSolder
SW105: BOOT; SKRPABE010
U101: RAK3172
U102: CH340E; MSOP-10_3x3mm_P0.5mm
U103: RainSun_Antenna
U104: ME6211C33M5G-N; SOT-23-5

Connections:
+3V3: C102.2, C103.2, C104.2, C107.2, J101.5, R101.1, R122.1, U101.24, U102.10, U104.5
/BUT2: R105.1, U101.19
/RESET: C101.2, J101.4, R101.2, U101.22
/SWCLK: J101.3, U101.8
/SWDIO: J101.2, U101.7
/UART2RX: R118.1, U101.1
/UART2TX: R119.1, U101.2
/USB+: R111.2, U102.1
/USB-: R110.2, U102.2
/VUSB: C105.2, C106.2, J104.A4, J104.A9, J104.B4, J104.B9, U102.7, U104.1, U104.3
GND: C101.1, C102.1, C103.1, C104.1, C105.1, C106.1, C107.1, D101.1, D102.1, D103.1, D104.1, D105.1, J101.1, J104.A1, J104.A12, J104.B1, J104.B12, J104.S1, R112.2, R113.2, SW105.2, U101.11, U101.17, U101.18, U101.23, U101.28, U102.3, U104.2
unnamed: D101.2, R114.2
unnamed: D102.2, R115.2
unnamed: D103.2, R116.2
unnamed: D104.2, R117.2
unnamed: D105.2, R122.2
unnamed: J104.A5, R112.1
unnamed: J104.A6, J104.B6, R111.1
unnamed: J104.A7, J104.B7, R110.1
unnamed: J104.B5, R113.1
unnamed: R114.1, U101.31
unnamed: R115.1, U101.32
unnamed: R116.1, U101.30
unnamed: R117.1, U102.6
unnamed: R118.2, U102.8
unnamed: R119.2, U102.9
unnamed: SW105.1, U101.21
unnamed: U101.12, U103.1

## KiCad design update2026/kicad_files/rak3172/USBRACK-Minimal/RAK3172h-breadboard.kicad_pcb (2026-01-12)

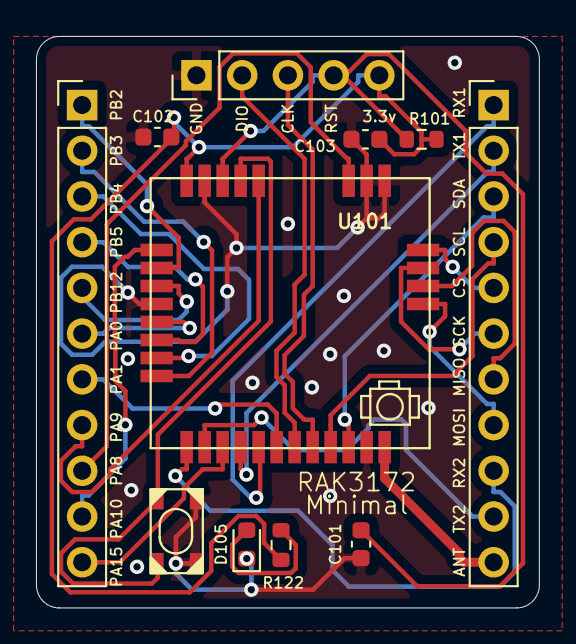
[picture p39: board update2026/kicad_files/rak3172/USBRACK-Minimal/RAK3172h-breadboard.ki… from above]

Board: 2 copper layers, 27.9 x 31.8 mm, 11 parts (0 on the bottom side), 29 nets.

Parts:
C101, C102: 100nF; C_0603_1608Metric
C103: 10uF; C_0603_1608Metric
D105: ON-LED; LED_0603_1608Metric
J101: Prog_cnx; PinHeader_1x05_P2.54mm_Vertical
J102: GPIOA; PinHeader_1x11_P2.54mm_Vertical
J103: GPIOB; PinHeader_1x11_P2.54mm_Vertical
R101: 10k; R_0603_1608Metric
R122: 330R; R_0603_1608Metric
SW105: BOOT; SKRPABE010
U101: RAK3172

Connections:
+3V3: C102.2, C103.2, J101.5, R101.1, R122.1, U101.24
/ANT: J103.11, U101.12
/CS: J103.5, U101.16
/MISO: J103.7, U101.14
/MOSI: J103.8, U101.13
/PA0: J102.6, U101.29
/PA1: J102.7, U101.6
/PA8: J102.9, U101.19
/PA9: J102.8, U101.20
/PA10: J102.10, U101.25
/PA15: J102.11, U101.3
/PB2: J102.1, U101.26
/PB3: J102.2, U101.32
/PB4: J102.3, U101.31
/PB5: J102.4, U101.30
/PB12: J102.5, U101.27
/RESET: C101.2, J101.4, R101.2, U101.22
/RX1: J103.1, U101.5
/SCK: J103.6, U101.15
/SCL: J103.4, U101.9
/SDA: J103.3, U101.10
/SWCLK: J101.3, U101.8
/SWDIO: J101.2, U101.7
/TX1: J103.2, U101.4
/UART2RX: J103.9, U101.1
/UART2TX: J103.10, U101.2
GND: C101.1, C102.1, C103.1, D105.1, J101.1, SW105.2, U101.11, U101.17, U101.18, U101.23, U101.28
unnamed: D105.2, R122.2
unnamed: SW105.1, U101.21
